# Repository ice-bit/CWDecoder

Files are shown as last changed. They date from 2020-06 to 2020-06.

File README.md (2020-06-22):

# CWDecoder

CWDecoder is a realtime _morsecode-to-ascii_ translator
for ATMega µC written in C.

<div align="center">
    
</div>

## Building
PCB layout has been tested and it's ensured that it works, if you wanna buy a copy of 
this decoder, compress _gerbers_ directory(`pcb/gerbers`) in a `zip` file and build it
from your favourite PCB manufacturing company(may i suggest you [JLCPCB](https://jlcpcb.com/)?).  
**NOTE**: PCB manufacturing companies will sell you just the circuit boards, **WITHOUT** any components on it, so you still need to buy elsewhere [components](#component-list) and solder them manually.

The code provided in this repository is adapted to the schematics, but it can be changed (for instance pin number of I/O devices) according to your needs.

### Schematics
KiCAD `.pro` project file can be found into `pcb` directory.  

<div align="center">
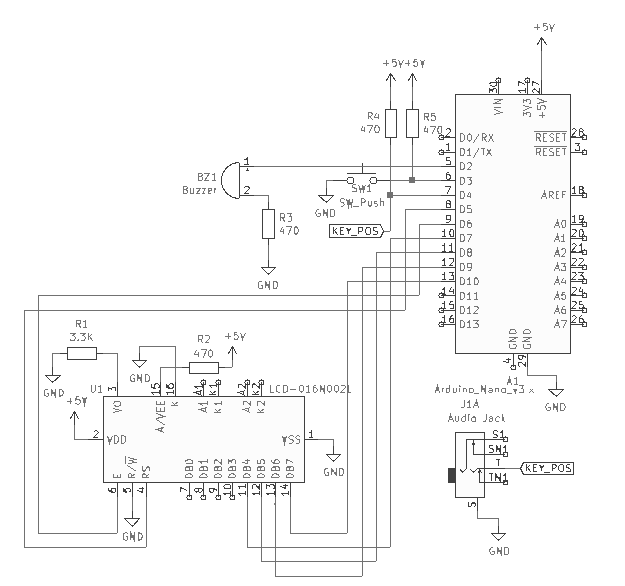
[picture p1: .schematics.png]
    
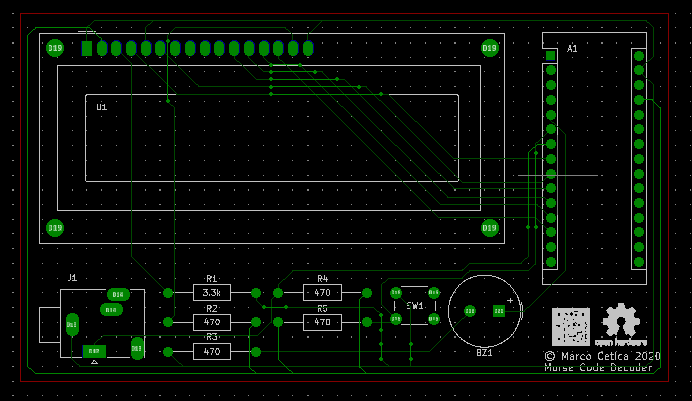
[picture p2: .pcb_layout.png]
    
</div>

### Component list
To build this project you will need the following components:  
- x4 470Ohm resistor;  
- x1 3.3kOhm resistor;  
- x1 3.5mm AudioJack connector;  
- x1 LCD1602 liquid crystal display;  
- x1 Arduino nano;
- x1 buzzer(maximum size: 12.2x6.5mm)  
- x1 push button

### Software
**NOTE:** In order to build it you will need the 
[Arduino SDK](https://www.arduino.cc/en/main/software) and the [LiquidCrystal Library](https://www.arduino.cc/en/Reference/LiquidCrystal).  
CWDecoder works in a very simple way, it constantly check if _button state_ has changed:
```c
    ...
    key.currentState = digitalRead(key.pin); // Retrieve key status
    if(key.currentState != key.prevState) {
        if(key.currentState == HIGH) { // If button state is HIGH
            // Start to beep and power on LED
            ...
            key.counter = millis(); // Record when button has been pressed
        } else if(key.currentState == LOW) {
            // If button has been released, then determines if it is a 'dit' or 'dat'.
        }
    }
```
 if so it determines whether the input is of _long_(ie a 'dah') or _short_ type(ie a 'dit'); to do so, when the button is released, it checks if _active time_(ie time when straight key is pressed)
 is greater than two constant fixed time(`shortPress` and `longPress`):
 ```c
    ...
    uint64_t currentTime = millis(); // Get current time
    // If button has been pressed enough time for a dit...
    if(((currentTime - key.counter) >= shortPress) && (currentTime - key.counter))
        buttonEvent(0); // ...Handle a dit
    else if((currentTime - key.counter) >= longPress) // Otherwise
        buttonEvent(1); // Handle a dat
    ...
 ```
At this point it calls `buttonEvent()` function, which add the proper symbol(ie a dot or a line) to a fixed size char buffer:
```c
    void buttonEvent(uint8_t type_of_event) {
        if(type_of_event == 0) // Short press
            buf[++pos] = '.';
        else if(type_of_event == 1) // Long press
        buf[++pos] = '-';
    }
```

Last but not least, after last function has returned, it sample the buffer if and only a certain amount of time
has passed. Without this mechanism, for instance, the program would not distinguish
between the letter 'e'(a single `dit` in morse code) and the letter 's'(three `dit` in morse code):
```c
    const short wpm = 500; // Words-per-minute 
     // If user hasn't touched key for enough time, then we can sample the buffer
    if((millis() - timeLast) > wpm)
        translate();
```
**NOTE**: words-per-minute value is **NOT** accurate, i found out that `500` is something like `~24wpm`.  
`translate()` function does the following:
```c
    char translatedWord = converter(buf); // Convert what's inside the buffer
    ...
    lcd.print(translatedWord); // Print ASCII character into the LCD.
```
After each letter has been translated, it empty the buffer to prevent buffer overflow.
In this way it's possible to use a tiny char buffer and save a lot of precious memory:
```c
    memset(buf, 0, sizeof(buf)); // reset buffer
    pos = -1; // Set index at the beginning
```

### Character support
By default CWDecoder support international alphabet(ie English alphabet) + 0-9 numbers. If you need special characters
(such as comma, period, blockquote, etc.) you can add them by adding new entry on `converter()` function:
```c
    ...
     else if(!strcmp(ch, "<morse_code>")) { return '<ascii_letter>'; }
    ...
```

## License
This project is been released under 
[GPLv3](https://choosealicense.com/licenses/gpl-3.0/) license.

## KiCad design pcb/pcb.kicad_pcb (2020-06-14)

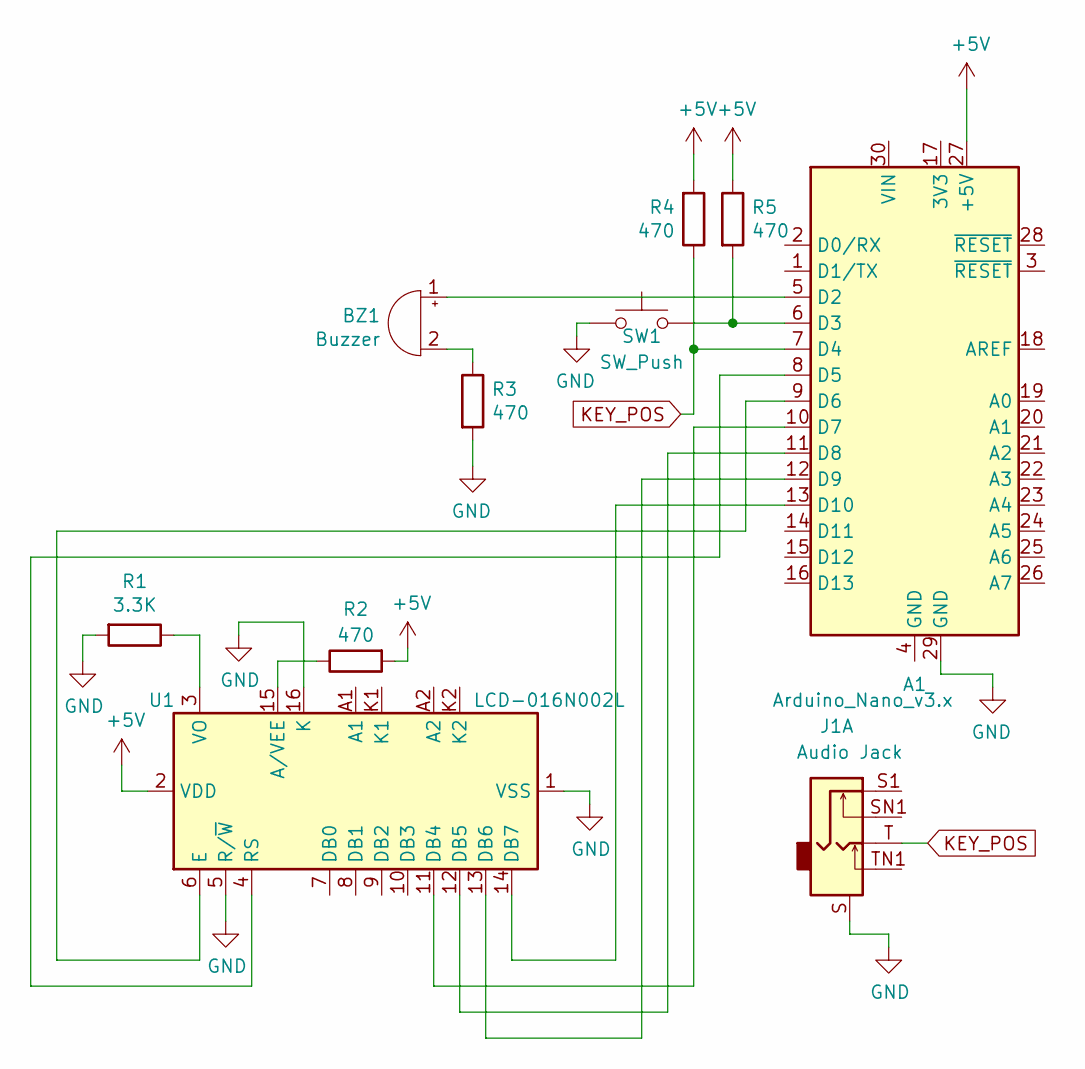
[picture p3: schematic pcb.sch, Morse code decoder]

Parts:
A1: Arduino_Nano_v3.x; Arduino_Nano
BZ1: Buzzer; Buzzer_TDK_PS1240P02BT_D12.2mm_H6.5mm
J1: Audio Jack; Jack_3.5mm_Ledino_KB3SPRS_Horizontal
R1: 3.3K; R_Axial_DIN0207_L6.3mm_D2.5mm_P15.24mm_Horizontal
R2, R3, R4, R5: 470; R_Axial_DIN0207_L6.3mm_D2.5mm_P15.24mm_Horizontal
SW1: SW_Push; SW_PUSH_6mm_H4.3mm
U1: LCD-016N002L; WC1602A

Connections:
+5V: A1.27 (+5V), R2.2, R4.2, R5.1, U1.2 (VDD)
GND: A1.29 (GND), J1.S, R1.2, R3.2, SW1.1, U1.1 (VSS), U1.5 (R/~W), U1.16 (K)
KEY_POS: A1.7 (D4), J1.T, R4.1
unnamed: A1.5 (D2), BZ1.1 (-)
unnamed: A1.6 (D3), R5.2, SW1.2
unnamed: A1.8 (D5), U1.4 (RS)
unnamed: A1.9 (D6), U1.6 (E)
unnamed: A1.10 (D7), U1.11 (DB4)
unnamed: A1.11 (D8), U1.12 (DB5)
unnamed: A1.12 (D9), U1.13 (DB6)
unnamed: A1.13 (D10), U1.14 (DB7)
unnamed: BZ1.2 (+), R3.1
unnamed: R1.1, U1.3 (VO)
unnamed: R2.1, U1.15 (A/VEE)

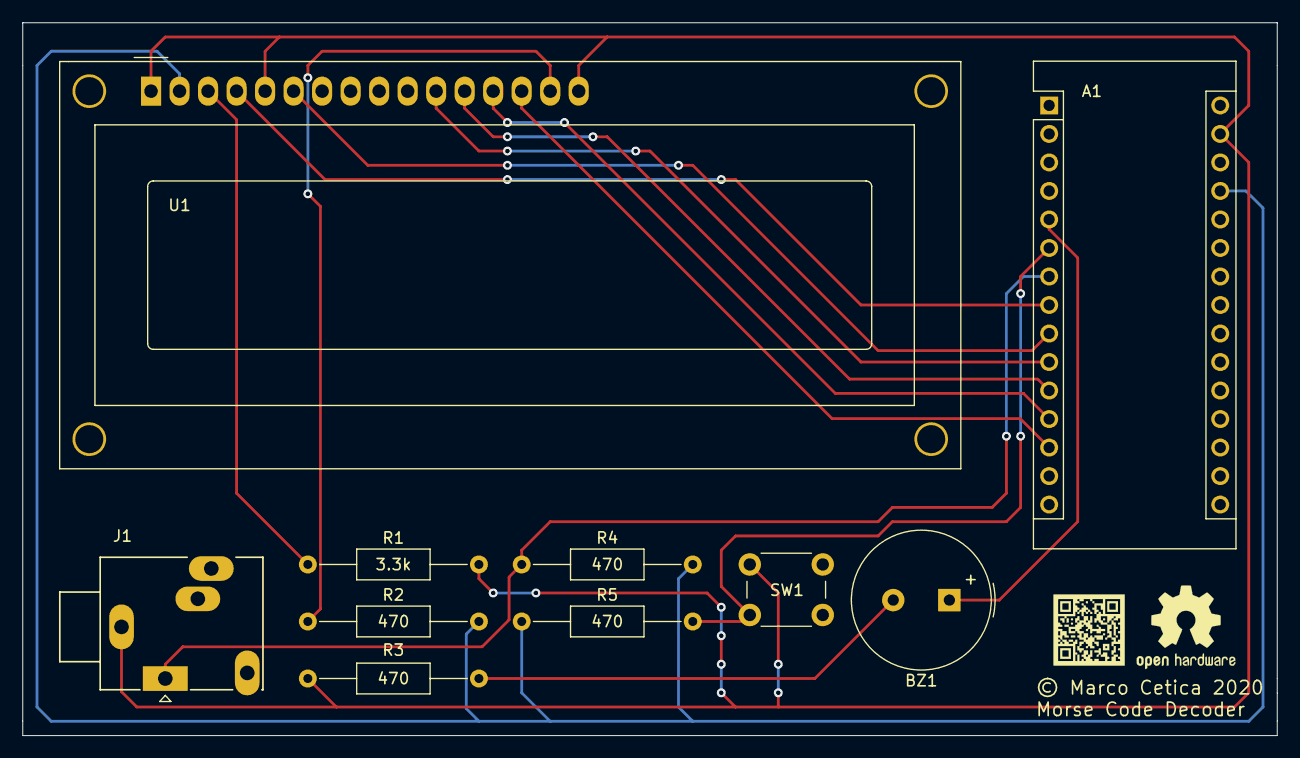
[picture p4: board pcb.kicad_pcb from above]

Board: 2 copper layers, 111.8 x 63.5 mm, 10 parts (0 on the bottom side), 14 nets.

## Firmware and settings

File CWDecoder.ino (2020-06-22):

#include <LiquidCrystal.h>
#define BUZZER_PIN 2 // Buzzer pin
#define KEY_PIN 4 // Straight key pin
#define RESET_PIN 3 // Reset push button
#define DELIM "*" // Delimiter to split a word
#define LCD_NUM_ROWS 2
#define LCD_NUM_COLS 16


typedef struct Button {
  const uint8_t pin = KEY_PIN;
  const uint8_t debounce = 10;
  uint64_t counter = 0; // How long button has been pressed
  // {prev,current}State variables are used to determine state switch
  uint8_t prevState = LOW; 
  uint8_t currentState;
} Button_t;

const uint8_t rs = 5, en = 6, d4 = 7, d5 = 8, d6 = 9, d7 = 10;
LiquidCrystal lcd(rs, en, d4, d5, d6, d7); // Setup display
Button_t key; // create a new button instance
const uint8_t shortPress = 50; // ms for a short press(dit)
const uint8_t longPress = 200; // ms for a long press(dah)
const uint16_t wpm = 500; // words-per-minutes(500 ~ 20 wpm, counter isn't accurate FIXME:)
uint64_t timeLast = 0; // ms since last word
bool alreadyTranslated = true; // To prevent adding sampling
int16_t pos = -1; // default value means empty buffer
char buf[10]; // A buffer to store data for conversion
uint8_t currentColNum; // Current column number
uint8_t currentRowNum; // Current row number

// Internal function
void buttonEvent(uint8_t type_of_event);
void translate();
char converter(const char *ch);

void setup() {
  pinMode(BUZZER_PIN, OUTPUT);
  pinMode(key.pin, INPUT);
  pinMode(LED_BUILTIN, OUTPUT);
  pinMode(RESET_PIN, INPUT);
  lcd.begin(16, 2);
  lcd.setCursor(0, 0);
  tone(BUZZER_PIN, 55000, 200); // beep for 200 ms at start
}

void loop() {

  // If reset button is pressed, reset lcd
  if(!digitalRead(RESET_PIN)) {
    lcd.clear();
    currentColNum = currentRowNum = 0;
  }

  // Read key current state
  key.currentState = !digitalRead(key.pin);

  // Check if state is changed
  if(key.currentState != key.prevState) {
    // Dirty hack for mechanical deboucing(a Schmitt trigger would be a better solution)
    delay(key.debounce);
    // In case of a bounce, update currentStatus
    key.currentState = !digitalRead(key.pin);
    if(key.currentState == HIGH) {
      // Start tone generator and turn on the LED
      tone(BUZZER_PIN, 55000);
      digitalWrite(LED_BUILTIN, HIGH);
      // Record when button was pressed
      key.counter = millis();
    } else if(key.currentState == LOW) {
      // Button is no longer pressed, get how long it was 
      // in previous state(ie how long it was pressed)
      uint64_t currentTime = millis();
      // If active key time is at least equal to short press time and lower than long press time 
      // then handle a short press event
      if(((currentTime - key.counter) >= shortPress) && (currentTime - key.counter) < longPress)
        buttonEvent(0); // Handle a short press
      else if((currentTime - key.counter) >= longPress) // Otherwise
        buttonEvent(1); // Handle a long press

      // Update time since last word
      timeLast = millis();
      // Disable tone generator and turn dff the LED
      noTone(BUZZER_PIN);
      digitalWrite(LED_BUILTIN, LOW);
    }
    // Then update previous state for the next iteration
    key.prevState = key.currentState;
  }

  /* if endTime-starTime (time since last keystroke)
  is greater than "word-per-minutes" time and 
  buffer is empty, translate the last word.
  Buffer must not be empty to prevent sampling
  when there are no data at all.
  Also, in order to prevent multiple sampling 
  we need a boolean flag */
  if(((millis() - timeLast) > wpm) && (pos != -1) && !alreadyTranslated) {
    translate();
    alreadyTranslated = true; // Set flag to true(i.e. do not add another marker)
  }

  /* Even if buffer overflows are very uncommon
    (since we empty the buffer after each word),
    a dumb user could write n characters one 
    behind the other(where n = sizeof(buf)). */
  if(pos >= 10) {
    memset(buf, 0, sizeof(buf));
    pos = -1;
  }
}

void buttonEvent(uint8_t type_of_event) {
  if(type_of_event == 0) { // short press
    buf[++pos] = '.'; // Add a 'dit' to the buffer
    alreadyTranslated = false; // Set flag to false(i.e. sample the word at next iteration)
  } else if(type_of_event == 1) { // long press
    buf[++pos] = '-'; // Add a 'dah' to the buffer
    alreadyTranslated = false; // Set flag to false(i.e. sample the word at next iteration)
  }
}

void translate() {
  // Translate word
  char translatedWord = converter(buf);

  if(currentColNum == 16) { // if we reached the end of current line
    if(currentRowNum == 1) { // and If we already are on second line
      lcd.clear(); // Clear the screen and set cursor to (0,0)
      currentColNum = currentRowNum = 0; // Reset counters
    } else { // otherwise just go to the next row
      currentColNum = 0; // Reset column pos
      lcd.setCursor(currentColNum, ++currentRowNum); // Set cursor at next line
    }
  }
  // print character to the screen
  lcd.print(translatedWord);
  // Go to the next column
  currentColNum++;
  // Empty buffer
  memset(buf, 0, sizeof(buf));
  pos = -1;
}

char converter(const char *ch) {
    // Letters
    if(!strcmp(ch, ".-")) { return 'a'; }
    else if(!strcmp(ch, "-...")) { return 'b'; }
    else if(!strcmp(ch, "-.-.")) { return 'c'; }
    else if(!strcmp(ch, "-..")) { return 'd'; }
    else if(!strcmp(ch, ".")) { return 'e'; }
    else if(!strcmp(ch, "..-.")) { return 'f'; }
    else if(!strcmp(ch, "--.")) { return 'g'; }
    else if(!strcmp(ch, "....")) { return 'h'; }
    else if(!strcmp(ch, "..")) { return 'i'; }
    else if(!strcmp(ch, ".---")) { return 'j'; }
    else if(!strcmp(ch, "-.-")) { return 'k'; }
    else if(!strcmp(ch, ".-..")) { return 'l'; }
    else if(!strcmp(ch, "--")) { return 'm'; }
    else if(!strcmp(ch, "-.")) { return 'n'; }
    else if(!strcmp(ch, "---")) { return 'o'; }
    else if(!strcmp(ch, ".--.")) { return 'p'; }
    else if(!strcmp(ch, "--.-")) { return 'q'; }
    else if(!strcmp(ch, ".-.")) { return 'r'; }
    else if(!strcmp(ch, "...")) { return 's'; }
    else if(!strcmp(ch, "-")) { return 't'; }
    else if(!strcmp(ch, "..-")) { return 'u'; }
    else if(!strcmp(ch, "...-")) { return 'v'; }
    else if(!strcmp(ch, ".--")) { return 'w'; }
    else if(!strcmp(ch, "-..-")) { return 'x'; }
    else if(!strcmp(ch, "-.--")) { return 'y'; }
    else if(!strcmp(ch, "--..")) { return 'z'; }
    // Numerals
    else if(!strcmp(ch, "-----")) { return '0'; }
    else if(!strcmp(ch, ".----")) { return '1'; }
    else if(!strcmp(ch, "..---")) { return '2'; }
    else if(!strcmp(ch, "...--")) { return '3'; }
    else if(!strcmp(ch, "....-")) { return '4'; }
    else if(!strcmp(ch, ".....")) { return '5'; }
    else if(!strcmp(ch, "-....")) { return '6'; }
    else if(!strcmp(ch, "--...")) { return '7'; }
    else if(!strcmp(ch, "---..")) { return '8'; }
    else if(!strcmp(ch, "----.")) { return '9'; }
}

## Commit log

2020-05-21 Fixed a strange bug
    [main.ino]
2020-05-30 Fixed a bug about spaces
    CWDecoder is now able to add spaces
    between words at the end of a word
    rather than at the beginning of a new
    one.
    [main.ino]
2020-05-31 Fixed LCD bug and added reset button
    [main.ino]
2020-06-04 Updated repo structure for Arduino Pro IDE
2020-06-04 Added schematics
    [pcb.kicad_pcb, pcb.sch]
2020-06-05 Completed schematics
    [pcb.sch]
2020-06-08 Finished schematics and added pcb layout
    [pcb.sch]
2020-06-08 Finished pcb wiring
    [pcb.kicad_pcb, pcb.sch]
2020-06-09 Redesigned pcb due to a bug
    [pcb.kicad_pcb, pcb.sch]
2020-06-10 rewired pcb
    [pcb.kicad_pcb]
2020-06-10 Added kicad library
2020-06-11 Update pin numbers
    [pcb.kicad_pcb, pcb.sch]
2020-06-13 Updated a footprint
    [pcb.kicad_pcb, pcb.sch]
2020-06-14 Added gerbers
    [pcb-B_Cu.gbr, pcb-B_Mask.gbr, pcb-B_Paste.gbr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]

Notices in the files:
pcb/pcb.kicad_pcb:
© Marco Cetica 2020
